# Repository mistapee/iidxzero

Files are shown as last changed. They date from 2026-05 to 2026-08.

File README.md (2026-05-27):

# iidxzero

You can buy cheap from OpenRhythmUK on Ebay (https://www.ebay.com/sch/i.html?_ssn=openrhythmuk) as usual. As much as the international shipping fee can be (realistically you still couldn't find cheaper) I am more than reasonable and a lot make contact about creating a bundle for them where not only do I discount everything, usually adding 2 or 3 more controllers doesn't change the shipping fee. I've given away a lot of bonus items for my own entertainment

17th May 2026 - Guide  for setting up with GP2040-CE firmware uploaded, plus 3D print files for a gasket and a case - the gasket is in place of washers between the PCBs, it is specifically 3mm and any washers I got just weren't. By going between the 2 PCBs we add a fair bit of strength to the top plate. It's a bit different here as we are not using hotswap sockets, so we don't have screw holes and the plate and PCB are fixed with the keys are soldered in.



The case has the same dimensions as the PCB so it will be difficult to insert the controller if you print it as it is - either sand the inside to allow enough gap for it to slide in, or slightly scale up the print. I used 100.2% and it has been perfect for all the controllers - the controller slides in easy and stays in, but I know from experience this might need tweaking for your own printer.

The only thing missing is a turntable, a 60mm diameter rotary encoder knob. You can find these in 3D print file archives, but I can not find them to purchase which I would rather do. I've got several different prototypes made and will update when I have achieved some clarity.

s4444-l1600

!10th May 2026 - they're made and being sent out - firmware used is GP2040-CE which is the aim every time really, the target price all together should be around 20 quid (that's GBP). I'll be testing the config backup in the next few days before uploading it, but the webconfig is reachable with the available keys as they are, I then set my buttons to be b1-b4 L1, R1, L2 S1 and S2, although that's mostly arbitrary it's the order GP2040-CE does it. i will also break down how the GPIO are used for setting up the key LEDs n the Add-Ons section, the 2 RGB LEDS and the rotary encoder settings - i set the encoder to act as Dpad up and down but there are other options, you should also set a reset time (in ms)  so it doesn't hold in whatever direction last pushed.

it's the brilliance of community efforts that give us so many opportunities, and i hope that by fulfilling a request i can further bring others in to making accessibility fun and rewarding.

To go with the PCBs you'll need 2x 5050 RGB, a PEC16 4015f encoder, 2x 0603 0.01uf capacitors for the encoder, 8x 0603 220o resistors (one for each key LED and one for the RGB line), 2x 4.5x4.5mm(5-7mm tall) tactile switches for s1 and s2, 7x keyboard switches (linear) and 7x 1.5u key caps. The turntable i made out of resin, you can get creative, it is basically a 60mm diameter encoder knob, but the resin has a good weight to it.

made by request but to my conditions of robustness - no folding or whatever. very cheap. can we agree the turntable is a gimmick?

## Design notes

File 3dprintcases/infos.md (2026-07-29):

This controller has been annoying to measure up cases for, part PCB tolerances from fab, and part 3D printer shenanigoats I think

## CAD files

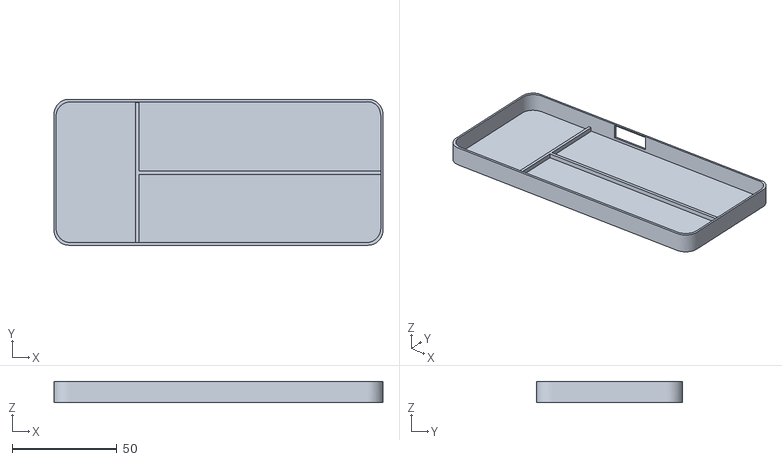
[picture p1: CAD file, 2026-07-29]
3dprintcases/!iidx_case-quicktoprint-157.25x69.57x10.05-.stl
157.2 x 69.6 x 10.1

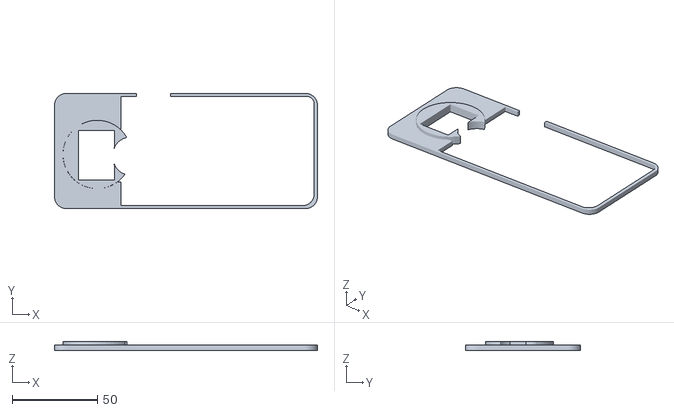
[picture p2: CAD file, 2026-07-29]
3dprintcases/!IIDX_case-gasket-New_July26.stl
154.0 x 67.5 x 5.00

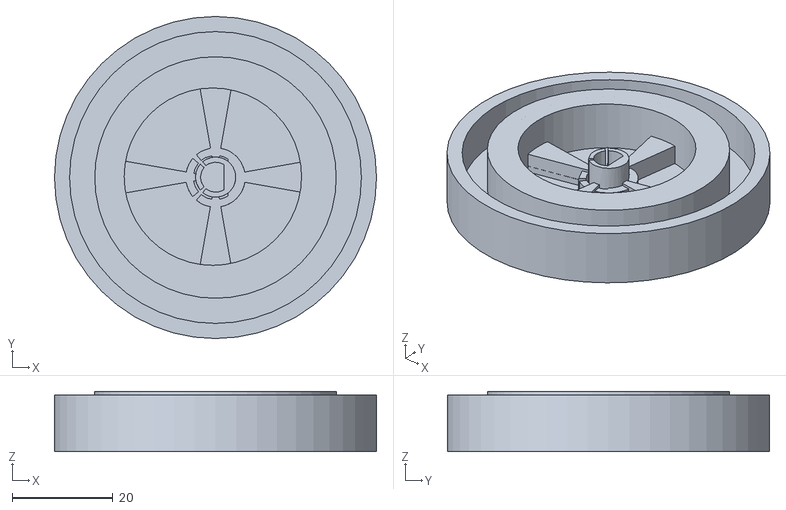
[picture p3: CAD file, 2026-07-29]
3dprintcases/!IIDX_turntable-test_but_simpler.stl
64.0 x 64.0 x 12.0

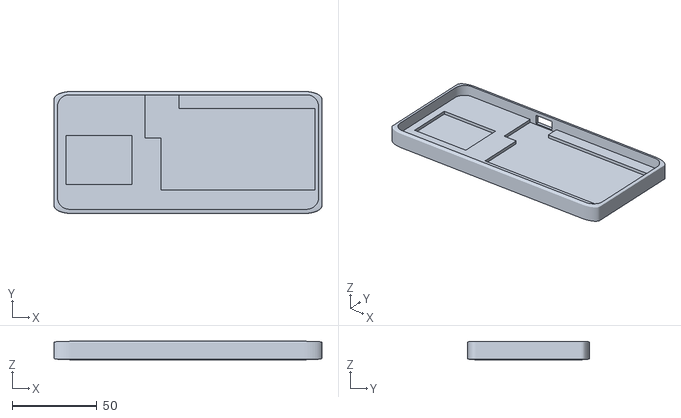
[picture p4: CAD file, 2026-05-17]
3dprintcases/!-IIDXzero_case.stl
158.0 x 72.0 x 10.9

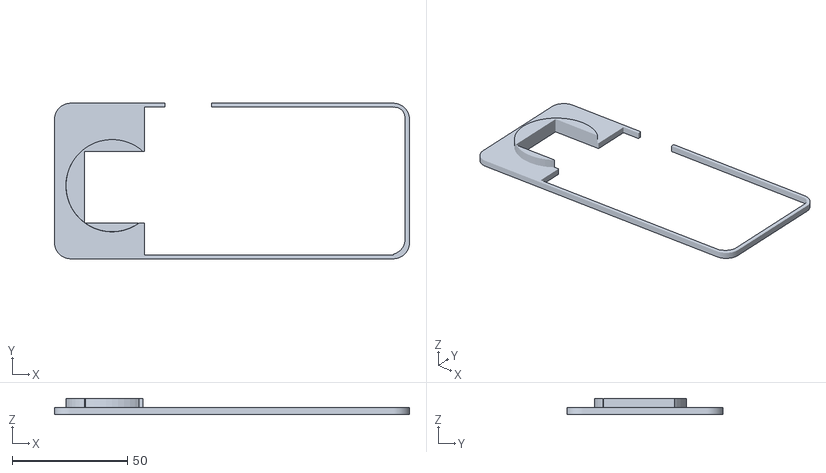
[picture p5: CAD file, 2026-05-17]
3dprintcases/!IIDXzero-Gasket.stl
154.0 x 67.5 x 7.00

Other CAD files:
3dprintcases/!IIDXzero-pushonknob_test.stl

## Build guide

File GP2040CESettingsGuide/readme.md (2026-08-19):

Specifics brought up by buyers:
Beatoraja - reset in to the GP2040-CE firmware (b3, b4, s2, it resets, go to 192.168.7.1) go to Add Ons, down to Rotary Encoders. Change my Dpad up/down to analogue Y. In Beatoraja keybind menu accessed by pressing 6. That should do you - I've not used Beatoraja in a very long time, got a message for help, this helped.

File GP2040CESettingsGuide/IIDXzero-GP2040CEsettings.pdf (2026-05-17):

Flash with GP2040-CE (specific version for Waveshare pico zero - normal Pico version will work but will auto assign various GPIO etc just confusing things)

Load webconfig by holding b3+b4+s2 (game controllers settings in windows will show you what buttons are 3, 4 and 8 as you press them, it’s a good time to get used to using this - after you have configured it b3+b4+s2 will be different). Webconfig then serves from the pico on 192.168.7.1

EVERY TIME YOU MAKE A CHANGE IN A SECTION CLICK SAVE, AND GO TO REBOOT - UNTIL YOU ARE FINISHED SELECT ‘WEB CONFIG’ AS YOUR REBOOT OPTION SO THAT YOU CAN GO TO 197.168.7.1 AGAIN AND CONTINUE SETUP!

Configuration > GPIO Pin Mapping
Set as shown, clear all others I’ve assigned them left to right b1, b2, b3, b4, l1, r1, l2 - and s1 and s2 are the tactile swiches

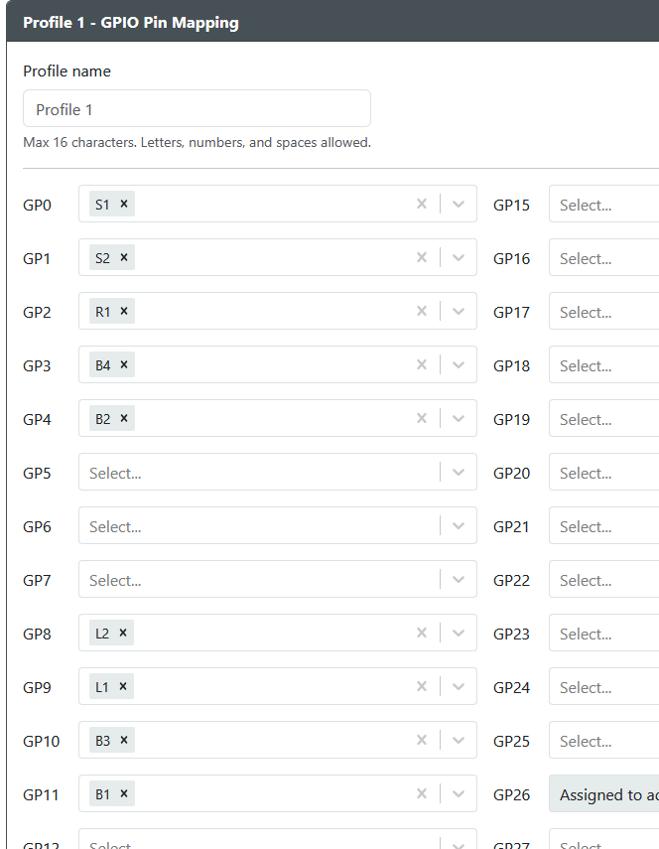
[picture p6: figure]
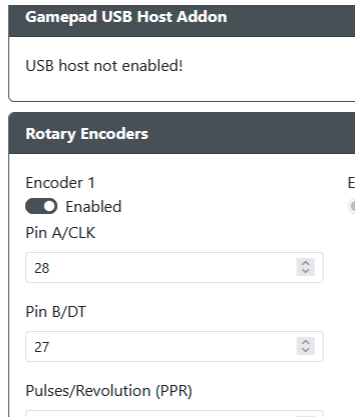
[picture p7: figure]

In configuration -> Add-ons Configuration

Rotary Encoders

Pin A and Pin B are GPIO 28 & 27, depending on which side of the turntable you place your hand up and down may be inverted for you, in which case switch these numbers over

Multiplier & Reset After {ms} Multiplier is down to personal preference, but likely doesn’t need to be changed (I’ve only used sim files in Project Outfox. Reset After sets the up/down of the turn table back to neutral after using it, otherwise if it is disabled (set to 0) it would continue to register the last direction input until engaged again, which likely isn’t hat you want.

Control Mode - the home controller, arcade controller, even DJ hero, use an optical sensor of sorts and merely acts as an up and down switch, so D-Pad up and down makes the most sense to me, but, you can set it to analogue if for some reason incremental input would be useful.

Allow Wrap-Around isn’t needed here, and if I click this the whole page goes goofy and won’t allow saving or anything. Just avoid it for now.

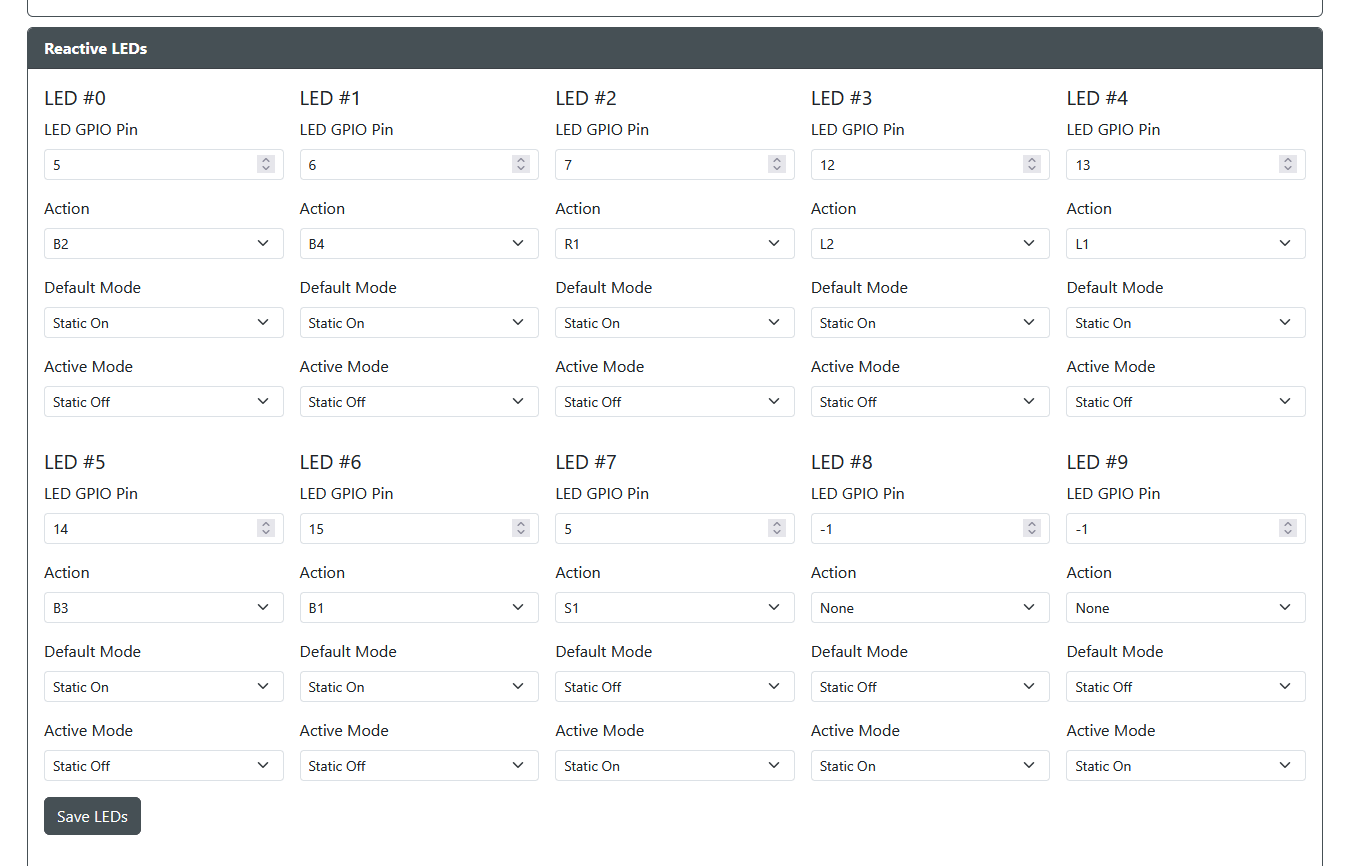
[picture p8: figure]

On the same page is the reactive LEDs section - set as shown for GPIO and Action, as those are the GPIO’s I chose making the PCB. In the picture it shows I have set the LEDs to be on until ‘active’ (pressed) at which point they will go off. Usually we do the opposite of this, you can if you want, just get the GPIO and ‘Action’ (assigned button) right as it is here.

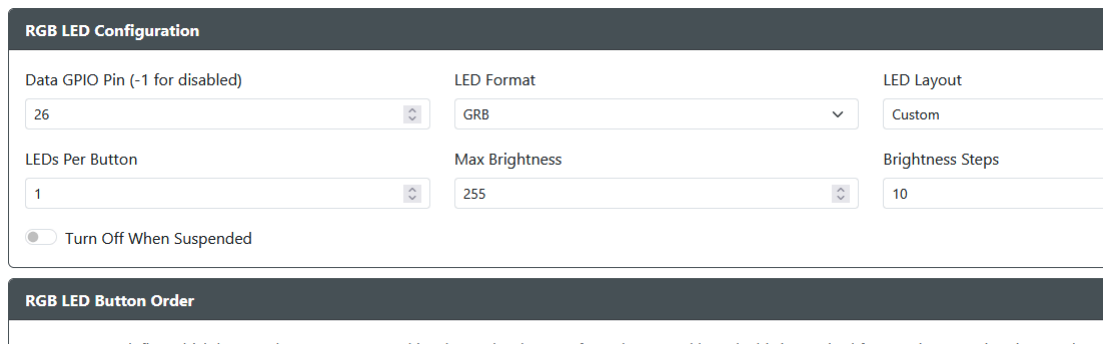
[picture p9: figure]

Configuration > LED
Configuration

This section can be a bit hard to understand, just duplicate what is shown here - make sure there are no buttons listed under ‘Assigned Buttons’

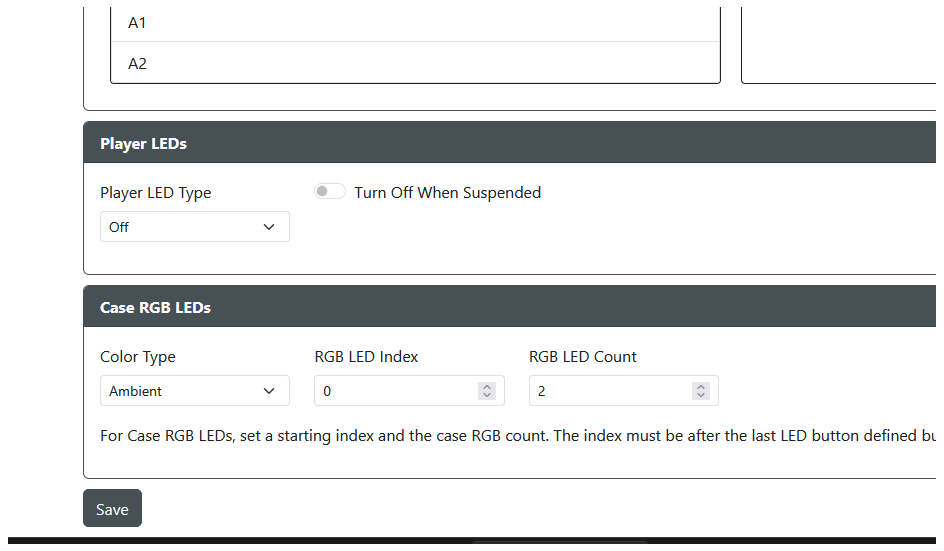
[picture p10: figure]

Lower on the same LED page. I haven’t documented how to make animations etc here but you can modify these and switch with them with hotkey combos documented in the GP2040-CE docs. For now just having it working will do, so copy this here,.

On this last reboot you can select to reboot as a controller. Badabing me ol’ china

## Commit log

2026-05-14 added fixed gerber with better footprints
2026-05-17 3d print files for gasket (between pcbs) and case
    By printing the case part at 100.2% scale i don't have to sand the printed part for the pcbs to drop in, the gasket does not need re-scaling
    [!-IIDXzero_case.stl, !IIDXzero-Gasket.stl]
2026-05-17 gasket for between pcbs, adds strength
2026-05-17 not sure on this... it works though
    [!IIDXzero-pushonknob_test.stl]
2026-07-29 moved !-IIDXzero_case.stl to 3dprintcases/!-IIDXzero_case.stl
    [!-IIDXzero_case.stl]
2026-07-29 moved !IIDXzero-Gasket.stl to 3dprintcases/!IIDXzero-Gasket.stl
    [!IIDXzero-Gasket.stl]
